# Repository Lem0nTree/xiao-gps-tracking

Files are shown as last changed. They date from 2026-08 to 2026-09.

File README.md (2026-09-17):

# XIAO GPS Tracker Smart Motion v2.1

**A compact, private, low-cost GPS tracker built from accessible maker hardware.**

The tracker logs positions locally without a SIM card, subscription, or cloud
account, then transfers them over bonded Bluetooth to an Android phone for
viewing or export.

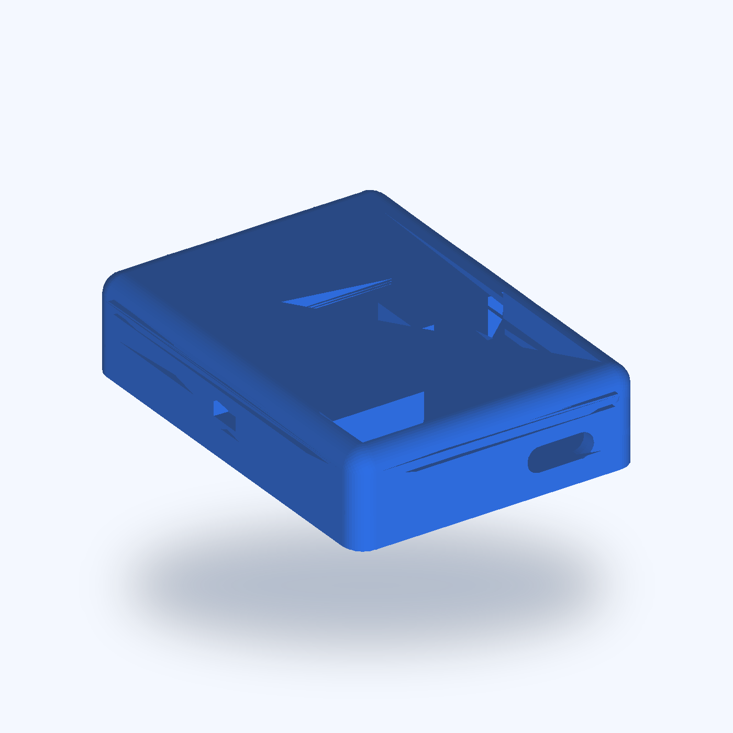
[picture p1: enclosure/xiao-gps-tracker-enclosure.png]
Render of the printable XIAO GPS Tracker enclosure


The assembled v2 hardware uses a Seeed Studio XIAO nRF52840, an ATGM336H GPS
receiver, a GY-521/MPU6050 motion sensor, a 1000 mAh 1S LiPo, and the native
Android companion app.

## Why this tracker?

- **No monthly fee** — no SIM card and no data plan.
- **Private by design** — tracks stay on the device and your phone.
- **Two recording modes** — Interval keeps scheduled logging; Smart Motion
  waits for sustained movement before acquiring a location.
- **Battery-conscious operation** — the firmware reduces receiver, UART, BLE,
  MCU, and flash activity where the assembled hardware permits.
- **Large offline history** — more than 104,000 positions fit in the onboard
  circular log.
- **Easy phone sync** — connect only when needed; logging continues without the
  phone.
- **Useful exports** — save a journey as GPX or CSV.
- **Open maps** — the app uses MapLibre and OpenFreeMap, with light and dark
  themes.
- **Pocket-size hardware** — an enclosure is included as STL, 3MF, and Fusion
  360 source.

## Smart Motion and Interval modes

Interval mode preserves the six saved schedules: 1, 15, or 30 minutes, or 1,
2, or 3 hours. Smart mode retains that saved interval but does not use the
interval scheduler while selected. A motion interrupt starts a short
accelerometer verification; sustained dynamic acceleration then starts GPS
acquisition, with a fresh valid location and UTC fix required before logging.
Smart Motion now has two tracking profiles:

- **Continuous** (default): the existing behavior, with a 120-second cooldown
  after a fix and another acquisition if movement continues.
- **Start & Stop** (Point-to-point): capture one point after confirmed movement starts, then
  one after **10 minutes without accelerometer activity**. Any new acceleration
  restarts the stop timer. No intermediate points are recorded. If movement
  resumes while acquiring the arrival point, that attempt is cancelled and a
  new ten-minute quiet period is required.

Point-to-point allows up to **5 minutes per GPS attempt**, requiring fresh GPS
position and UTC, at least **6 satellites**, and **HDOP ≤ 1.50**. These stricter
criteria favor better fixes; actual accuracy depends on reception. A failed
start attempt still waits for the stop; a failed arrival attempt rearms for the
next journey. It does not repeatedly retry while stationary. Both profiles keep
five-second motion confirmation and the saved sensitivity (Balanced by default).

Select **Smart motion → Tracking profiles** in the Android app. Point-to-point
requires app and firmware **2.1.0**. The updated app can still configure older
firmware using Continuous; it explains when a firmware update is needed. Older
apps retain log sync and Interval commands, but cannot read the new Smart status
or select Point-to-point. The detailed state machine, BLE packet layout, and
migration rules are in the [firmware notes](firmware/README.md).

## Actual v2 power and wiring model

The assembled hardware connects both the GPS receiver and the MPU6050 to the
XIAO `3V3` rail. It has a common ground, a 1000 mAh 1S LiPo connected to the
XIAO battery input, and no boost converter, load switch, GPS ON/OFF lead, or
physical GPS power gate. GPS supply is therefore electrically present whenever
the XIAO 3V3 rail is active.

Firmware reports these concepts separately:

- **Physical supply:** the receiver supply on this build; always connected
  while the XIAO rail is active.
- **Receiver activity:** whether the receiver is actively producing navigation
  data or is in a verified receiver-side standby state.
- **UART/parser activity:** whether the firmware has opened the GPS UART and is
  accepting NMEA data.

The firmware may probe the receiver's CASIC timed-standby capability after NMEA
has been established. It uses the optimization only after two complete
standby/resumption checks with valid navigation data; otherwise it keeps the
receiver running as required and reports that standby is unavailable. This is
an optimization, not a Smart-mode dependency. Current draw, standby timing,
and battery runtime still require physical measurement on the assembled unit.

## What you need

AliExpress changes listings and sellers frequently, so these are non-affiliate
search links rather than endorsements of a particular shop.

| Component | What to look for | AliExpress |
| --- | --- | --- |
| Seeed Studio XIAO nRF52840 | Standard nRF52840 board; Sense is not required | [Search](https://www.aliexpress.com/w/wholesale-xiao-nrf52840.html) |
| ATGM336H GPS receiver | 3.3 V-compatible module with `VCC`, `RX`, `TX`, and `GND` | [Search](https://www.aliexpress.com/w/wholesale-atgm336h-gps-module.html) |
| GY-521 / MPU6050 | Breakout with `VCC`, `GND`, `SDA`, `SCL`, and `INT` | [Search](https://www.aliexpress.com/w/wholesale-mpu6050-gy-521.html) |
| 1000 mAh 1S LiPo | Cell compatible with the XIAO battery input and enclosure | [Search](https://www.aliexpress.com/w/wholesale-1000mah-3.7v-lipo-battery.html) |

> [!IMPORTANT]
> Check dimensions, pin labels, logic levels, polarity, and the cell's charger
> requirements before ordering. Similar-looking marketplace modules are not
> always electrically equivalent.

## How it works

1. In Interval mode, the GPS obtains a position at the saved schedule and the
   XIAO saves it to onboard flash.
2. In Smart mode, the MPU6050 identifies a motion candidate, firmware verifies
   sustained movement, and the GPS obtains a fresh fix before a point is
   stored.
3. The Android app connects over bonded BLE to sync, browse, and export the
   route. Logging does not require the phone to remain connected.

The first bonded phone becomes the owner. A hardware recovery procedure can
change the owner without erasing the route history or saved wake settings.

## Android companion app

The Android app (`2.1.2`, versionCode `23`) shows tracker status, the
Interval/Smart selector, tracking profiles, map, and time-based route timeline.
Choose the GPS mode first: Interval shows the logging interval controls, while
Smart shows tracking profiles and hides the interval controls. The saved
interval is preserved and shown again when returning to Interval mode.
The dashboard separates tracker status, recording settings, and route history.
Its content scrolls on smaller screens while Connect and Sync remain accessible
at the bottom. Map gestures stay within the map; swipe outside it to scroll the
dashboard. Smart headlines show the motion state independently of GPS standby,
and any cooldown duration is explicitly the last value reported by the tracker.
It syncs the local log over BLE and exports tracks as GPX or CSV without sending
them to a cloud service. It also reports runtime fallback and receiver standby
capability when the firmware provides those statuses.

<p align="center">
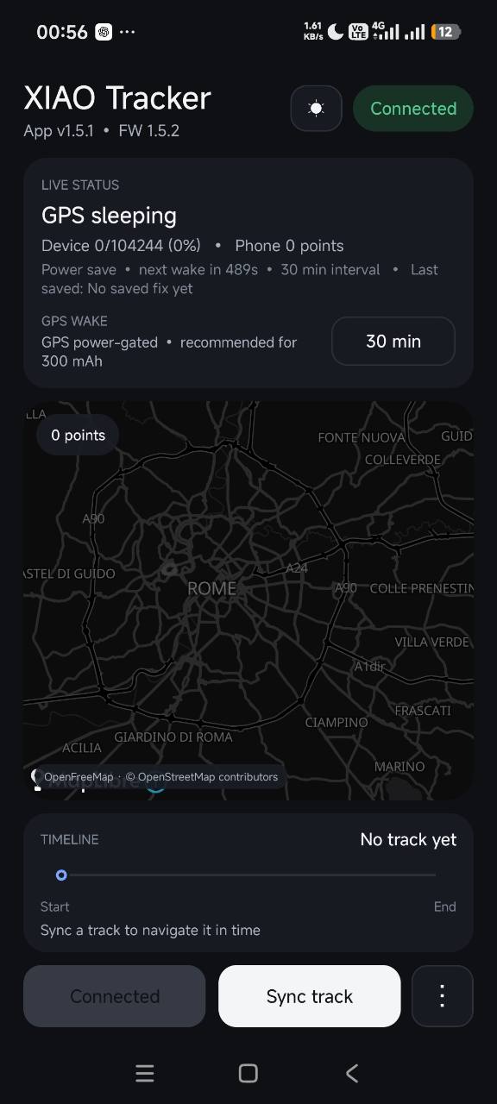
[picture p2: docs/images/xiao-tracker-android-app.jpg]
Earlier XIAO Tracker app interface, before the dashboard refresh
  
</p>

The screenshot above shows the earlier interface; an updated device capture is pending.

## Included in this repository

```text
firmware/   Arduino firmware, setup notes, and detailed wiring
android/    Native Android companion app
enclosure/  STL, 3MF, Fusion 360 source, render, and render script
docs/       README images and project media
```

### Start here

- [Firmware setup and technical details](firmware/README.md)
- [1000 mAh LiPo wiring guide](firmware/WIRING_1000MAH.md)
- [Android project](android/XiaoGpsTrackerApp)
- [Printable enclosure](enclosure/Seeed_GPS_Tracker.stl)
- [Release notes](RELEASE_NOTES.md)

For the firmware, use the non-mbed **Seeed nRF52 Boards** Arduino core and
change the example BLE pairing PIN before flashing. The Android project targets
JDK 17.

## Storage capacity

The tracker holds 104,244 GPS points before its circular log overwrites the
oldest entries. The table below applies to scheduled Interval mode; Smart mode
is event-driven, so its history length depends on movement and fix frequency.

| Interval mode setting | On-device history |
| --- | ---: |
| 1 minute | 72 days |
| 15 minutes | 3.0 years |
| 30 minutes | 5.9 years |
| 1 hour | 11.9 years |
| 2 hours | 23.8 years |
| 3 hours | 35.7 years |

Points already synced to Android remain in the phone archive even after the
tracker eventually overwrites its oldest records.

## Validation status

The software release defines the v2 state machine, BLE extension, metadata
migration, and runtime capability reporting. Physical validation is still
pending: sensor identity/address/interrupt checks, GPS 3.3 V operation and
NMEA checks, CAS12 standby cycles, current measurements, and sensitivity
calibration on the assembled hardware. No battery-runtime or power-saving
measurement is claimed yet. See [VALIDATION.txt](VALIDATION.txt) for the
release checklist.

This is a personal/offline logger, not a live anti-theft or emergency tracker:
it has no cellular connection and does not continuously report its location to
a remote service.

## Future development

The current BLE tracker is the foundation for planned variants built around the
same compact, local-first platform. These ideas are a roadmap and are **not
implemented in the current release**.

### RF version

- Add a **LoRa radio** for long-range, low-power position and status
  communication beyond normal Bluetooth range.
- Explore **Meshtastic integration** so compatible nodes can relay tracker data
  through an off-grid LoRa mesh.
- Retain local flash logging when a radio link or gateway is unavailable.

### SIM version

- Integrate a **SIM800L GSM/GPRS module** for remote position updates where
  compatible 2G service is still available.
- Add store-and-forward behavior so the tracker can upload queued positions
  after coverage returns.
- Redesign the power stage for the SIM800L's transmission-current peaks.

> [!NOTE]
> SIM800L depends on 2G service, which has already been retired in some
> countries and networks. Regional network compatibility must be checked before
> developing or buying parts for this variant.

### Long-autonomy version

- Replace the pouch cell with a protected, quality **18650 Li-ion cell** for
  substantially more stored energy.
- Develop a larger enclosure with safe cell retention and service access.
- Profile every always-on load and tune the GPS, BLE, LoRa, or Meshtastic duty
  cycle for extended unattended operation.

Future autonomy targets will be published only after complete hardware builds
have been measured under representative conditions.

## License

See [LICENSE](LICENSE).

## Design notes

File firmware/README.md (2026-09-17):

# XIAO GPS Tracker firmware

Technical setup notes for the Seeed Studio XIAO nRF52840 firmware. For the
project overview and Android app, return to the [main README](../README.md).

## Arduino setup

Use the non-mbed **Seeed nRF52 Boards** Arduino core and select:

```text
Tools -> Board -> Seeed nRF52 Boards -> Seeed XIAO nRF52840
```

Install these Arduino libraries:

1. TinyGPSPlus
2. Adafruit SPIFlash
3. Adafruit TinyUSB Library

Open [XiaoGpsTracker/XiaoGpsTracker.ino](XiaoGpsTracker/XiaoGpsTracker.ino).
Arduino Serial Monitor uses **115200 baud** and the GPS UART uses **9600 baud**.

Before deployment, change the example six-digit BLE pairing PIN:

```cpp
static const char BLE_PAIRING_PIN[] = "482731";
```

## Actual v2 wiring

The assembled build uses a 1000 mAh 1S LiPo, a GY-521/MPU6050 at I²C address
`0x68`, and an ATGM336H receiver powered from the XIAO `3V3` rail. Grounds are
common. The GPS supply is continuously connected while the XIAO 3V3 rail is
active; this build has no boost converter, load switch, GPS ON/OFF lead, or
physical GPS power gate.

| XIAO pin or rail | Connect to | Notes |
| --- | --- | --- |
| `BAT` | LiPo positive; LiPo negative to `GND` | 1S cell; check polarity and charger suitability |
| `3V3` | MPU6050 `VCC` and GPS `VCC` | Use the documented 3V3 rail |
| `GND` | MPU6050 `GND` and GPS `GND` | One common ground |
| `D2` | MPU6050 `INT` | Motion interrupt |
| `D4` | MPU6050 `SDA` | I²C data |
| `D5` | MPU6050 `SCL` | I²C clock |
| `D6` | GPS `RX` | XIAO TX -> receiver RX |
| `D7` | GPS `TX` | Receiver TX -> XIAO RX |
| `D0` | Owner-reset test point | Hold to `GND` during boot for 5 seconds |
| `D1` | No connection | Unused/reserved for a future design |
| `D3`, `D8`–`D10` | No connection | Free in the assembled build |

Leave the GY-521 `AD0`, `XDA`, and `XCL` pins unconnected. The default `AD0`
state selects address `0x68`. Leave GPS `PPS` unconnected unless a future
firmware design explicitly uses it.

See the detailed [1000 mAh LiPo wiring guide](WIRING_1000MAH.md) before
connecting power. Do not connect a battery, sensor, or receiver through D1;
there is no external power-control circuit in this assembly.

## Recording modes

The persisted wake modes are:

```text
WAKE_MODE_INTERVAL = 0
WAKE_MODE_SMART    = 1
```

### Interval mode

Interval mode retains the existing six persisted schedules:

```text
1 minute
15 minutes
30 minutes (default)
1 hour
2 hours
3 hours
```

The GPS obtains a valid location for each scheduled point. The legacy
`CMD_SET_INTERVAL` command also selects Interval mode, preserving the expected
behavior of older Android apps.

### Smart Motion mode

Smart mode leaves the saved interval untouched but does not use the interval
scheduler while selected. An MPU6050 interrupt moves the tracker from `ARMED`
to `VERIFYING`. Verification samples dynamic acceleration (gravity removed) at
20 Hz for 5 seconds, or 100 samples. A candidate is accepted when at least 60
samples are active and no quiet gap exceeds 1 second. A rejected candidate
returns to `ARMED` without a GPS acquisition.

#### Continuous profile (default)

An accepted candidate moves to `ACQUIRING`. Firmware requires a fresh valid
location and UTC from the GPS within 90 seconds, then stores the point and
enters a 120-second cooldown. Recent accelerometer activity and reliable GPS
speed/displacement determine whether movement continues. Continued movement
can start another acquisition; when movement stops, the tracker returns to
`ARMED`. A failed acquisition is retried after the cooldown only when movement
is reconfirmed.

#### Point-to-point profile

After the same five-second acceleration confirmation, capture one departure
point. Then enter `WAITING_FOR_STOP` with GPS parsing inactive. Every subsequent
MPU motion event resets the stop timer; there is no two-minute capture in this
profile. After exactly 600 seconds with no accelerometer activity, enter
`ACQUIRING_STOP` and attempt one arrival point. GPS speed and drift do not reset
the acceleration timer. A GPS fix also does not reset it.

Each acquisition allows **300 seconds**, instead of Continuous's 90 seconds.
It requires a fresh post-start location and UTC plus all of these conditions:

- location, date, time, satellite count, and HDOP no older than 2 seconds;
- at least 6 satellites;
- HDOP greater than zero and no greater than 1.50.

These limits favor higher-quality navigation but do not guarantee positional
accuracy. A fix arriving at or after the acquisition deadline is not stored.
A failed departure attempt still waits for arrival. A successful or timed-out
arrival rearms for the next departure; no repeated stationary attempts occur.
If acceleration resumes during arrival acquisition, cancel that acquisition
before storing a point and wait for another complete ten-minute quiet period.
Point-to-point does not use CAS12 cooldown slices and retires any in-flight
startup probe before its departure acquisition.
Booting or changing settings rearms the runtime; in-progress journeys are not
persisted across reboot.

The Android Smart Motion settings display **Tracking profiles** with
**Continuous** and **Point-to-point**. Sensitivity remains an underlying saved
calibration setting; the new app preserves it when changing profile.

Smart sensitivity presets are starting calibration values, not measured final
thresholds:

| Preset | Wire value | Starting dynamic-acceleration threshold |
| --- | ---: | ---: |
| High | `0` | 80 mg |
| Balanced (default) | `1` | 160 mg |
| Low | `2` | 300 mg |

The firmware initializes the MPU by direct register access, checks identity and
critical register read-back, and arms its interrupt. If that initialization or
the interrupt fails, the saved Smart selection is preserved but that boot runs
Interval behavior and reports `runtimeIntervalFallback`.

### Motion rearm diagnostic build

The current startup banner is `FW diagnostic build: ble-startup-1`. The
post-v2.0 motion-rearm diagnostics remain available. Serial output now includes saved mode, actual runtime
mode, fallback, Smart state, the real Smart cooldown, D2 level, interrupt count,
motion-event count, and verification sample counts/rejection reasons. An
Interval `nextWake` countdown is printed only when Interval actually runs.
The legacy INFO wake countdown is zero while Smart runs; use Smart Info for
its cooldown. Android's displayed state is the last BLE read-back, not a
continuous live indication.

The patch recovers a latched-high MPU interrupt even when the rising edge was
missed, checks the Seeed core's interrupt attachment result, checks interrupt
clearing failures, and rearms the sensor on return to ARMED. Continued movement
at a successful fix's cooldown expiry starts the next acquisition directly.
Data-ready interrupts supply verification timing; software no longer discards
fresh samples just because readout jitter makes successive reads less than
50 ms apart.

The armed profile uses `DLPF_CFG=0`, `MOT_DUR=1` per the low-power motion
configuration flow in the [InvenSense product specification, section 8.1](https://hw101.tbs1.de/mpu6050/doc/mpu6050.pdf).
This replaces the initial plan's 100-count hardware-duration setting: that
setting is not validated as a 100 ms debounce in 5 Hz cycle mode. The
five-second software confirmation remains the sustained-movement filter.
The candidate threshold follows that flowchart's 32 mg/LSB scale, rounding
down to codes 2/5/9 for High/Balanced/Low. The previous Balanced code of 80
would correspond to 2560 mg at that scale. Documentation revisions disagree
on motion-threshold units; actual module calibration is still pending. The
software verifier retains the exact 80/160/300 mg presets regardless of the
hardware wake threshold.

Run the focused host regression checks from the repository root:

```sh
python3 firmware/tests/test_motion_runtime.py
python3 firmware/tests/test_tracking_profiles.py
```

These compile actual scheduler/verifier and profile/GPS-save function bodies
with GCC/G++ and fake peripherals/clock. They cover repeated cooldowns, motion after
rearming, missed interrupt edges, jittered 20 Hz samples, quiet rejection,
failure retry, rollover, Interval scheduling, Point-to-point stop timing and
cancellation, quality gating, metadata migration, and settings rollback. They do not validate the
physical MPU, GPS, BLE stack, or flash writes.

## GPS activity and CAS12 standby

The firmware keeps these states distinct:

- **Physical supply:** electrically present on `3V3` whenever the XIAO rail is
  active; there is no physical GPS power-off control on this hardware.
- **Receiver activity:** whether the ATGM336H is navigating or in receiver-side
  timed standby.
- **UART/parser activity:** whether `Serial1` is open and NMEA is being
  accepted by the firmware.

After normal NMEA has been observed, firmware can probe the receiver's CASIC
`$PCAS12` timed-standby capability. It attempts two controlled standby cycles
and accepts the capability only if each cycle shows the expected NMEA silence,
resumption, fresh RMC/GGA sentences, and subsequent valid navigation. A failed
probe is marked unavailable for the boot; it is not continuously retried.
When unavailable, the receiver remains active as required and the status does
not claim a power saving that was not verified. CAS12 is an optimization only;
Smart motion and GPS acquisition do not depend on it.

Standby slices may be selected from the firmware's short/medium/long profiles
(30, 60, or 120 seconds). Thirty seconds is a compatibility workaround, not a
claim that it is optimal. Slice current and resume latency must be measured on
the actual receiver before choosing a production default.

## Storage and metadata

The XIAO's 2 MiB QSPI flash contains a circular log with 104,244 records. Each
20-byte record contains:

- sequence number;
- UTC Unix timestamp;
- latitude and longitude multiplied by 10^7;
- HDOP multiplied by 100;
- satellite count;
- CRC-8.

The 32-byte metadata record is version 3. It retains the owner identity and
interval and uses three previously reserved bytes for `wakeMode`,
`smartSensitivity`, and `trackingProfile`. Version-1 metadata migrates to
Interval/Balanced/Continuous while preserving owner and interval. Version-2
metadata preserves mode and sensitivity and defaults to Continuous, regardless
of the old reserved profile byte. Valid v1/v2 settings are decoded in RAM
without any flash erase/write during boot. The next successful settings or
owner save persists metadata v3. An optional format upgrade therefore cannot
prevent Bluetooth startup if the stored settings can already be read.
GPS records remain byte-for-byte compatible.

Owner reset (D0 held low during boot) clears only ownership. It preserves the
route history, interval, wake mode, sensitivity, and tracking profile. Clearing
the route also preserves these settings; neither operation is a factory reset.

## BLE framing and profile protocol v3

Packets use the existing frame:

```text
magic A5 5A | type:u8 | len:u16 little-endian | payload | CRC16-CCITT
```

The CRC covers `type`, `len`, and `payload`. Existing command and response
types remain available, including the 65-byte `INFO` response. Command IDs
remain the same as v2:

```text
CMD_GET_SMART_INFO   = 0x06   payload: empty
CMD_SET_SMART_CONFIG = 0x07   payload: mode:u8, sensitivity:u8, profile:u8
RSP_SMART_INFO       = 0x85   payload: exactly 13 bytes, protocolVersion = 3
```

`CMD_SET_SMART_CONFIG` returns the normal ACK and the client reads Smart Info
back to verify persisted settings. The v3 command requires three bytes;
legacy two-byte commands remain accepted and explicitly select Continuous.
Profile values are `0` Continuous and `1` Point-to-point. Invalid values or
lengths are rejected before any settings change.

The v3 `RSP_SMART_INFO` keeps the v2 field offsets and appends the profile:

| Offset | Field | Encoding |
| ---: | --- | --- |
| 0 | `protocolVersion` | `u8` |
| 1 | `mode` | `u8` (`0` Interval, `1` Smart) |
| 2 | `sensitivity` | `u8` preset (`0` High, `1` Balanced, `2` Low) |
| 3 | `motionState` | `u8` state code |
| 4 | `confirmationSeconds` | `u8` |
| 5 | `standbySliceSeconds` | `u8` |
| 6–7 | `fixCooldownSeconds` | `u16` little-endian; 120 Continuous, 0 Point-to-point |
| 8–9 | `cooldownRemainingSeconds` | `u16` little-endian |
| 10 | `flags` | `u8` bit field |
| 11 | `lastWakeReason` | `u8`; 0 none, 1 motion, 2 retry, 3 stop |
| 12 | `trackingProfile` | `u8`; 0 Continuous, 1 Point-to-point |

Motion state codes 0–5 retain their v2 meanings; 6 is `WAITING_FOR_STOP` and
7 is `ACQUIRING_STOP`. The cooldown remaining field describes only a Continuous
cooldown, not the Point-to-point quiet timer.

The defined flag bits are:

```text
0x01 MPU_PRESENT
0x02 MPU_INTERRUPT_ARMED
0x04 CAS12_VERIFIED
0x08 CAS12_ACTIVE
0x10 RUNTIME_INTERVAL_FALLBACK
0x20 GPS_RECEIVER_ACTIVE
```

There is deliberately no physical-GPS-power-off flag for this assembly. A
runtime fallback means the saved Smart setting remains available for a later
boot or hardware configuration; it does not silently rewrite the user's mode.

Older apps can still bond, read the legacy INFO packet, sync records, clear
logs, and set the six interval values. They cannot configure or display Smart
profiles or parse the v3 Smart Info until upgraded to app 2.1.0. The updated
app also accepts the v2 12-byte Smart Info, uses legacy setters for that
firmware, and offers Continuous only until firmware is upgraded.

## BLE behavior and security

The first successfully bonded phone becomes the owner. Tracker commands require
an encrypted, bonded owner connection. Unknown or unbonded phones are
disconnected. The app disconnects after BLE inactivity so the phone need not
stay connected while logging.

To replace the owner phone without deleting GPS history or wake settings:

1. Power off the tracker.
2. Connect **D0 to GND**.
3. Power or reset it and hold D0 low for at least five seconds.
4. Release D0.
5. Pair the replacement phone.

## Bluetooth startup diagnostics

Firmware 2.1.1 verifies the BLE stack, UART service, advertising payload, and
advertising start result. Serial output claims advertising only after a
successful start. With USB connected, open Serial Monitor at 115200 baud and
restart the tracker. A `FATAL:` line identifies a startup stage that failed;
these lines repeat every five seconds. In normal operation, `BLE DIAG` reports
`advertising=0/1` and `connected=0/1` every five seconds alongside GPS status.
Firmware 2.1.2 uses startup banner `flash-wake-1`. Pairing PINs are not logged.

An MCU reset or USB firmware upload does not necessarily remove power from
the onboard flash. The chip can remain in deep power-down while the sketch's
RAM state resets. Firmware 2.1.2 sends `0xAB` (Release from Deep Power-down)
using GPIO SPI **before** initializing QSPI, then waits 50 microseconds before
flash detection. This also avoids initializing the QSPI controller against an
unresponsive sleeping chip. The wake operation does not erase stored data.
See the [Puya P25Q16H datasheet](https://www.puyasemi.com/download_path/%E6%95%B0%E6%8D%AE%E6%89%8B%E5%86%8C/Flash%20%E8%8A%AF%E7%89%87/P25Q16H_Datasheet_V2.1.pdf),
pages 44–46 (`tRES1` maximum 8 microseconds).

For an enclosed tracker reporting `FATAL: P25Q16H QSPI flash not detected`,
upload firmware 2.1.2 normally over USB; battery removal and access to the
reset button are not required for this recovery path. Android 2.1.1 remains
compatible. Successful startup prints `QSPI JEDEC=0x856015` for P25Q16H and
then `Advertising as XIAO-GPS`. If initialization still fails, copy the new
repeating `FATAL: QSPI flash not detected after wake` line, including its
`JEDEC` and `read` fields. A completed ID transfer alone does not prove that
a flash chip responded.

The Android 2.1.1 scanner preserves scan failures and connection/disconnection
messages after discovery; its 12-second “not found” timeout applies only to the
scan that is still active. These diagnostics distinguish no advertisements
from a discovered tracker whose connection or pairing subsequently failed.

## Validation status

Source-level protocol, metadata, and state-machine checks can be performed
without a board. Physical validation remains pending for the assembled unit:
MPU `WHO_AM_I`, address, register read-back, and interrupt; GPS 3.3 V operation,
UART/NMEA, and valid navigation; two CAS12 standby/resumption cycles; current
draw in Interval and Smart states; and sensitivity calibration while stationary,
walking, in a city, and in smooth driving. See [VALIDATION.txt](../VALIDATION.txt)
for the release checklist. Do not use software defaults as measured hardware
results.

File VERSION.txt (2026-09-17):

XIAO GPS Tracker Smart Motion
Firmware: 2.1.2
Android app: 2.1.2
Android versionCode: 23
Wake modes: Interval (0), Smart motion (1)
Protocol INFO: 65-byte layout unchanged
Protocol commands: CMD_GET_SMART_INFO 0x06; CMD_SET_SMART_CONFIG 0x07
Protocol v3 response: RSP_SMART_INFO 0x85 (13-byte payload; profile at byte 12)
CMD_SET_SMART_CONFIG payload: mode:u8, sensitivity:u8, profile:u8 (3 bytes)
Legacy 2-byte config accepted; selects Continuous
Default GPS interval: 1800 seconds (30 min)
Default Smart sensitivity: Balanced (160 mg starting value)
Tracking profiles: Continuous (0), Point-to-point (1); default Continuous
Point-to-point: 600s quiet stop timer; 300s acquisition; >=6 sats, HDOP<=1.50
Metadata: version 3 on save; valid v1/v2 loaded read-only during boot
Metadata fields: wakeMode + smartSensitivity + trackingProfile in reserved bytes
Hardware: 1000 mAh 1S LiPo; GY-521/MPU6050 @0x68; GPS on 3V3; D1 unused

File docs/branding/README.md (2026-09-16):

# Launcher icon

A white location pin flows into a route with a sky-blue endpoint, on cobalt blue.
No text, Wi-Fi arcs, shadows, or baked-in texture.

## Files

- `generated-concept.png`: selected concept from the built-in image_gen tool.
- `launcher.svg`: clean, manually reconstructed vector artwork for deterministic exports.
- `launcher-preview.png`: 512px preview rendered from that SVG.
- `../../android/XiaoGpsTrackerApp/app/src/main/res/drawable/ic_launcher_foreground.xml`:
  matching Android vector, with 108dp layers and artwork inside the central 66dp circle.
- `mipmap-anydpi-v26`: adaptive launcher resources for Android 8+.
- `mipmap-anydpi-v33`: explicit monochrome layer for supported themed launchers.
- Density PNGs: standard and circular compatibility icons, 48/72/96/144/192px.

Android's [adaptive icon guidance](https://developer.android.com/develop/ui/compose/system/icon_design_adaptive)
defines layer geometry, mask safety, and monochrome behavior. The vector foreground
has transparent negative space; the launcher applies its own mask to the solid background.
The two-color foreground's alpha also supplies the themed monochrome silhouette.

## Regenerate compatibility PNGs

Install `@resvg/resvg-js@2.6.2` in a temporary directory outside the project, then run:

```sh
node scripts/render_launcher_icons.cjs /path/to/node_modules/@resvg/resvg-js
```

Keep the paths and scale in the SVG and Android vector in sync. Only exports use
rounded/circular masks; the adaptive background remains full-bleed.
The app manifest and application ID are unchanged. Only an APK update is needed.

## Image-generation provenance

Skill: imagegen. Mode: built-in tool, not API/CLI fallback. The generated raster
was used as the design reference; native vectors remove artifacts and guarantee
sharp edges and predictable launcher masking.

Initial prompt:

> Use case: logo-brand. Asset type: production Android adaptive launcher icon foreground for XIAO GPS Tracker. Create ONE polished, minimal, flat graphic symbol: a bold white GPS location pin whose lower tip flows into a short rounded winding route, ending in one small sky-blue waypoint dot. The pin has a clean genuinely transparent circular cutout. Strong simple silhouette, smooth precise edges, chunky strokes legible at 48 pixels, balanced negative space. Existing app uses cobalt blue and white. This foreground will be placed over a solid cobalt blue background by Android. Canvas: square 1024 x 1024 with a GENUINELY TRANSPARENT background and alpha channel, not a checkerboard painting. Center the complete symbol, including route and dot, entirely inside a central circle of diameter 580 pixels; generous transparent margins on all four sides are mandatory for Android adaptive icon masks. White main mark, pale sky-blue waypoint accent only. No text, no letters, no WiFi arcs, no satellite drawing, no maps, no border, no rounded-square tile, no background, no shadow, no glow, no texture, no 3D, no mockup, no watermark. Deliver a single finished foreground asset, not a sheet of options.

Final refinement prompt (input: first generated foreground):

> Refine this image into a finished production Android launcher icon. Keep exactly the location-pin flowing into a short curved route ending in a sky-blue dot, but fix all ragged edges and stray pixels: perfectly smooth flat graphic silhouette, opaque pure-white mark with a perfectly circular clean opening. Replace ALL transparency, holes, exterior and background with a uniform solid cobalt blue #225DD8. Absolutely no flecks, texture, noise, shadows, glow or gradients. Full-bleed square blue canvas, no rounded corners, no border, no mockup. Center and scale the entire white symbol and dot so ALL non-blue artwork fits inside the central circular safe area whose diameter is 58% of canvas width. The background fills the whole canvas edge to edge. No text or extra elements. Deliver a single clean square icon.

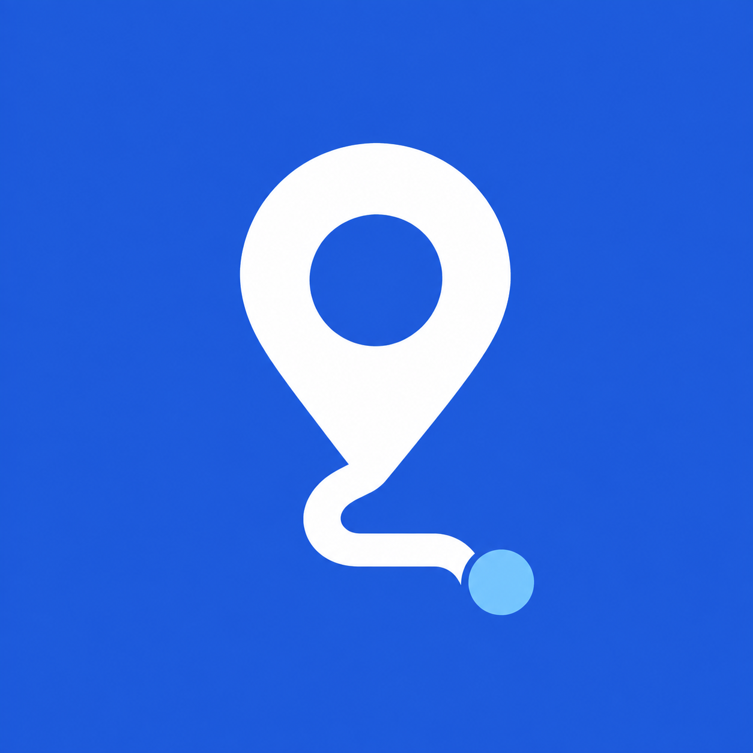
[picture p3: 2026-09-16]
docs/branding/generated-concept.png

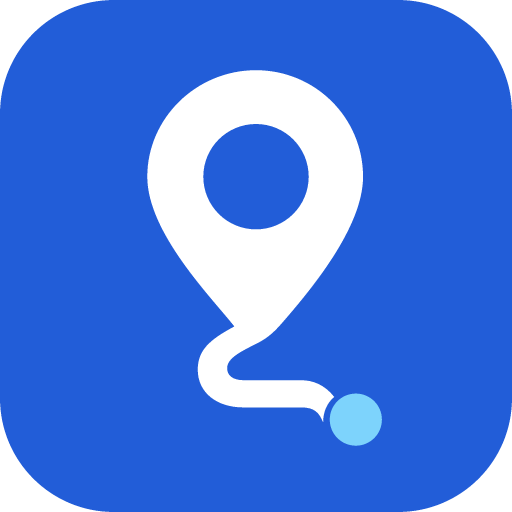
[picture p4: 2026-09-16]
docs/branding/launcher-preview.png

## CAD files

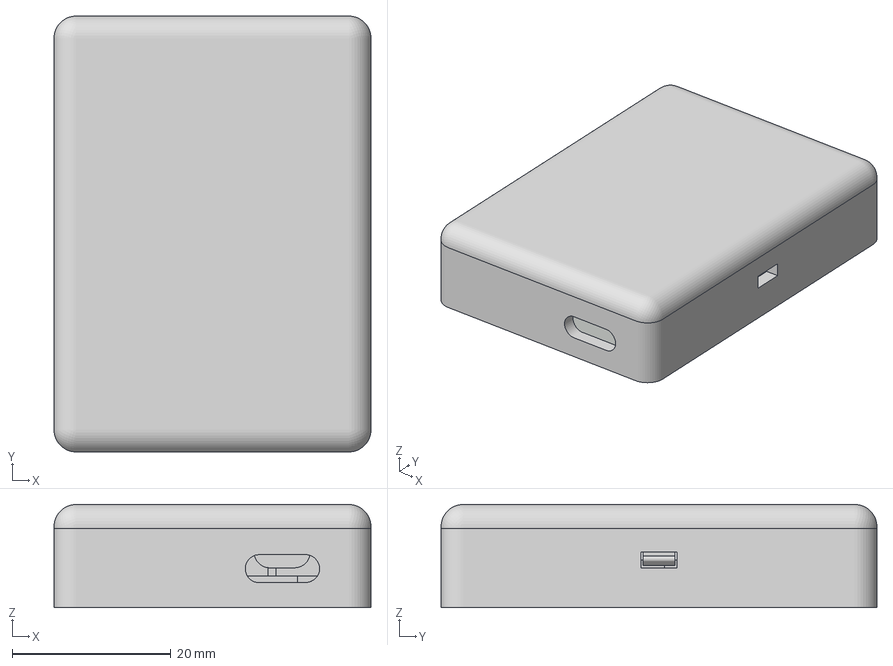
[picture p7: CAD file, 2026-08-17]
enclosure/Seeed_GPS_Tracker.3mf
40.0 x 55.0 x 13.0 mm
top

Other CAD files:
enclosure/Seeed_GPS_Tracker.f3z
enclosure/Seeed_GPS_Tracker.stl

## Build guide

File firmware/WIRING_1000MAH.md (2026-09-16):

# 1000 mAh LiPo wiring

This guide matches the assembled Smart Motion v2 hardware: a 1S 1000 mAh LiPo,
an XIAO nRF52840, a GY-521/MPU6050, and an ATGM336H GPS receiver. The receiver
and motion sensor share the XIAO `3V3` rail and ground.

## Connections

```text
1000 mAh 1S LiPo
   +------------------------------> XIAO BAT
   +------------------------------> XIAO GND (LiPo negative)

MPU6050 / GY-521                  XIAO
VCC -----------------------------> 3V3
GND -----------------------------> GND
SDA -----------------------------> D4 / SDA
SCL -----------------------------> D5 / SCL
INT -----------------------------> D2

ATGM336H GPS                      XIAO
VCC -----------------------------> 3V3
GND -----------------------------> GND
TX  -----------------------------> D7 / RX
RX  <----------------------------- D6 / TX
PPS -----------------------------> not connected

Owner-reset test point: D0 -> GND only when performing the boot reset procedure
D1: not connected (unused/reserved)
```

The GY-521 default I²C address is `0x68`; leave `AD0`, `XDA`, and `XCL`
unconnected. D3 and D8–D10 are free in this assembly.

## Power and signal checks

- Verify the LiPo connector polarity before connecting it to the XIAO battery
  input. Do not connect the raw cell to the sensor or GPS signal rail.
- Confirm that the GPS and MPU VCC pins are on XIAO `3V3`, with one common
  ground.
- GPS serial communication is 9600 baud. Cross TX and RX as shown above.
- D1 is unused. Do not wire it to a supply, receiver control input, or another
  power circuit.
- This assembly has no boost converter, load switch, GPS ON/OFF connection, or
  physical GPS power gate. The GPS supply is electrically present whenever the
  XIAO 3V3 rail is active.
- Check the cell manufacturer's permitted charge profile and the charger's
  suitability before charging. Do not charge a damaged, swollen, or unprotected
  LiPo cell.

Firmware can reduce UART/parser and receiver activity and may use CASIC timed
standby only after a runtime capability probe. Those logical states are not a
physical removal of GPS supply.

## Validation status

The wiring is the documented target assembly; physical checks remain pending.
Before relying on the tracker, verify MPU identity/address/register read-back
and interrupt operation, GPS 3V3 operation and NMEA/navigation, and the two
CAS12 standby/resumption cycles. Measure whole-device current in both wake
modes and calibrate Smart thresholds on representative stationary, walking,
city, and smooth-driving runs. No current, runtime, or calibration result is
claimed by this wiring guide.

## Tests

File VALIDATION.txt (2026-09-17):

XIAO GPS Tracker Smart Motion v2.1 validation record

This record separates software/source checks from tests that require the
assembled hardware. It contains no measured current, runtime, or calibration
result.

FLASH STARTUP RECOVERY 2.1.2 (2026-09-17)

OBSERVED - User's serial trace repeats "FATAL: P25Q16H QSPI flash not detected".
           This locates the reported failure before metadata loading and BLE.
           The metadata-migration simulation below is a separate defect, not
           the startup stage failing in this trace.
PASS - Source/dependency review: firmware puts the flash in deep power-down;
       Adafruit SPIFlash 5.1.1 attempts JEDEC detection without first waking
       it. The RAM sleeping flag resets independently of externally powered
       flash, and Seeed core QSPI activation can time out while it sleeps.
PASS - Target build with Seeed nRF52 1.1.13, Seeeduino:nrf52:xiaonRF52840:
       172776 bytes program, 19380 bytes RAM.
PASS - Existing motion runtime and tracking profile host suites after patch.
PASS - test_flash_startup.py compiles the actual startup functions against a
       GPIO/flash model: original detection fails asleep; patched warm resets,
       cold boot and repeated resets pass, and absent flash still fails.
       Checks mode-0 0xAB framing, pin directions, CS byte boundary and wake
       delay before QSPI ownership. No erase/write API is available to the fake.
PASS - Independent review of wake timing, board pins and QSPI handover.
PENDING - On-device recovery following USB upload, with the battery connected.
          No physical tracker is attached to this build host. The trace does
          not by itself distinguish a sleeping chip from hardware/board issues.

ANDROID APK 2.1.1 BUILD (2026-09-16)

PASS - Installed a local headless ARM64 toolchain and completed a clean Gradle
       assembleDebug plus testDebugUnitTest: 44 tasks, all 11 tests passed.
       Uses API 36, Build Tools 35.0.0, OpenJDK 21, and AGP-matched Google AAPT2
       through QEMU user mode (Debian's ARM64 AAPT2 cannot read API 36 resources).
PASS - APK signature verified by apksigner; packaged version 2.1.1/code 22.
       This supersedes the earlier missing-SDK build blockers below.

BLUETOOTH STARTUP / SCAN FIX 2.1.1 (2026-09-16)

PASS - Reproduced against firmware 2.1.0 in the fake-flash host harness:
       valid v2 metadata plus an erase failure makes loadOwnerLock fail,
       which setup treats as fatal before Bluetooth starts.
PASS - Patched firmware loads valid v1/v2 metadata without erases or writes,
       preserving original flash bytes and owner/settings even when writes
       fail. An explicit successful settings save still upgrades to v3.
PASS - Existing firmware motion/profile host suites pass after the repair.
PASS - Target build with Seeed nRF52 1.1.13, Seeeduino:nrf52:xiaonRF52840:
       172488 bytes program, 19380 bytes RAM.
PASS - Android protocol/presentation JVM suite: 11 tests (Kotlin 2.3.0,
       JUnit 4.13.2), including tracking-profile compatibility.
PASS - Changed BleManager compiles against Android API 36 and AndroidX Core
       1.17.0. Independent source review confirms active-session checks and
       timeout cancellation for discovery, scan failure, stop and restart.
BLOCKED - Full Android Gradle test/APK build: no configured Android SDK.
          JVM tests and the direct BleManager compile do not cover real BLE.
ADDED - Checked BLE stack/service/advertising initialization and repeating
        fatal-stage output; periodic actual advertising/connection diagnostics.
PENDING - Physical confirmation of the reported connection problem: no board
          USB serial trace or radio observation is available in this workspace.
          The simulated startup failure is established; it is not proof that
          flash writes failed on the user's tracker.

POINT-TO-POINT PROFILE (2026-09-16)

PASS - Firmware 2.1.0 target build with Seeed nRF52 core 1.1.13,
       Seeeduino:nrf52:xiaonRF52840: 172040 bytes program, 19380 bytes RAM.
PASS - python3 firmware/tests/test_motion_runtime.py: actual scheduler/verifier
       bodies pass Continuous regressions plus Point-to-point movement without
       periodic GPS, exact 600-second stop, motion cancellation during arrival,
       five-minute timeouts, quiet-clock rollover, and zero timestamp handling.
PASS - python3 firmware/tests/test_tracking_profiles.py: actual persistence and
       GPS-save bodies pass v1/v2 migration, profile reload, owner-reset
       preservation, invalid configuration rejection, failed-save RAM rollback,
       fresh quality filtering, one departure/arrival, deadline ordering, and
       cancellation of a startup CAS12 probe before endpoint acquisition.
       GCC/G++ tests use fake peripherals; C++ compiler unpacked under /tmp.
PASS - Firmware review confirms 13-byte Smart Info v3, profile at byte 12,
       legacy 2-byte setter selects Continuous, v3 3-byte setter validates
       profile before saving. GPS record and INFO layouts remain unchanged.
PASS - Android ProtocolTest and TrackerPresentationTest: all 11 JUnit tests
       passed using Kotlin 2.3.0 compiler, JVM target 17, JDK 21, JUnit 4.13.2.
       This standalone run compiled GpsRecord, Protocol, TrackerPresentation,
       and both test classes; it does not compile the Activity or Android UI.
PASS - Android resource XML parses; independent review checked profile dialog,
       legacy-firmware gating, status presentation, and profile-aware readback.
BLOCKED - Full Android Gradle unit-test/APK build: temporary JDK runs Gradle,
          but task dependencies fail because the Android SDK is unavailable.
PENDING - Physical departure/arrival tests, smooth travel vs no acceleration,
          real GPS availability/accuracy, stop/resume near the 10-minute
          boundary, power-cycle persistence, and phone-to-board BLE readback.

Entries below record earlier releases/changes and their original test results.
Where behavior changed, the Point-to-point entry above supersedes them.

ANDROID LAUNCHER ICON REFRESH (2026-09-16)

PASS - Resource XML parses. Native SVG and Android vector use identical paths.
PASS - Adaptive resources for API 26 and explicit themed monochrome resources
       for API 33 resolve to the new foreground and background.
PASS - All ten standard/round density PNGs have the expected 48/72/96/144/192 px
       dimensions and transparent corners. Rendered artwork stays inside the
       adaptive 33 dp safe radius (measured maximum approximately 30.58 dp).
PASS - Visual inspection of the rendered 512 px preview and 48 px round icon.
PENDING - Android build and launcher/device checks; Java/JDK unavailable here.
          See docs/branding/README.md for design sources and regeneration.

ANDROID DASHBOARD REFRESH (2026-09-16)

PASS - Static resource checks: XML parsing, unique view IDs, single ScrollView
       child, bottom action buttons outside the scroll area, mode selector
       before conditional interval controls, 48 dp minimum button targets,
       and status text without line truncation.
ADDED - TrackerPresentationTest covers motion headlines, receiver-state
        independence, sensor faults, fallback priority, and Interval behavior.
BLOCKED - APK compilation and JUnit execution: Java/JDK is absent on this host.
PENDING - Device/emulator visual and gesture checks: light/dark themes, 320 dp
          screen width, landscape, large fonts, map pan/pinch vs page scrolling,
          empty/populated route, BLE reconnect, and mode switching.

MOTION REARM PATCH (2026-09-16)

PASS - Host checks execute extracted production scheduler/verifier bodies with
       a fake clock and peripherals, compiled with GCC. Focused checks cover
       latched-high IRQ recovery, jittered verification, three consecutive
       120-second cooldowns, stopped/restarted motion, failed-fix retry,
       millis rollover, stationary quiet-gap rejection, obsolete Interval
       deadline isolation, normal Interval wake, and I2C failure fallback.
       Run: python3 firmware/tests/test_motion_runtime.py
PASS - Actual MPU profile functions tested with fake registers: low-power
       settings, 20 Hz verification profile, and status-clear I2C failures.
PASS - The pre-patch HEAD fails the latched-high interrupt recovery test;
       the modified source passes it (test script --baseline reproduces).
PASS - Diagnostic build motion-rearm-1 compiled for
       Seeeduino:nrf52:xiaonRF52840, core 1.1.13, Arduino CLI 1.5.1,
       TinyGPSPlus 1.0.3 and Adafruit SPIFlash 5.1.1:
       171016 bytes program storage, 19380 bytes dynamic memory.
PENDING - Reproduce the reported one-fix-then-stuck failure and verify the
          corrected behavior on the user's assembled tracker. Host tests do
          not establish physical interrupt delivery or sensor calibration.

IMPLEMENTED / SOURCE-CONTRACT CHECKS

PASS - Release identifiers are firmware 2.0.0, Android 2.0.0, versionCode 20.
PASS - Wake modes are Interval = 0 and Smart = 1; the six persisted Interval
       values remain 60, 900, 1800, 3600, 7200, and 10800 seconds.
PASS - Smart mode retains the saved interval while selected; legacy
       CMD_SET_INTERVAL (0x05) selects Interval mode.
PASS - v2 protocol IDs are CMD_GET_SMART_INFO = 0x06,
       CMD_SET_SMART_CONFIG = 0x07, and RSP_SMART_INFO = 0x85.
PASS - CMD_SET_SMART_CONFIG has exactly the two-byte mode:u8,
       sensitivity:u8 payload; RSP_SMART_INFO has exactly 12 bytes in the
       documented field order.
PASS - The legacy 65-byte INFO response and existing log record layout remain
       compatible with earlier clients.
PASS - Metadata version 2 consumes two reserved bytes for wakeMode and
       smartSensitivity; version-1 migration defaults to Interval/Balanced and
       preserves owner identity and interval.
PASS - Owner reset clears ownership only and preserves route history, interval,
       wake mode, and Smart sensitivity. Clear-log preserves wake settings.
PASS - Smart source contract covers MPU candidate interrupt, 20 Hz / 5-second
       dynamic-acceleration verification, fresh UTC location acquisition, and
       cooldown/reconfirmation behavior.
PASS - GPS status distinguishes physical supply, receiver activity, UART/parser
       activity, and timed standby; no physical-GPS-power-off capability is
       claimed for the assembled wiring.

NOT PERFORMED / PENDING HARDWARE VALIDATION

PENDING - Inspect the physical assembly: 1000 mAh 1S LiPo to XIAO BAT/GND;
          MPU VCC/GND to 3V3/GND, SDA D4, SCL D5, INT D2, address 0x68; GPS
          VCC/GND to 3V3/GND, TX to D7, RX from D6; D1 unused.
PENDING - On the real MPU6050, verify WHO_AM_I, I²C address, critical register
          read-back, data-ready configuration, and the D2 interrupt.
PENDING - On the real GPS, verify 3.3 V operation, 9600-baud UART wiring,
          NMEA reception, valid RMC/GGA navigation, and fresh UTC fixes.
PENDING - Runtime CAS12 capability check: after normal NMEA, complete two
          controlled standby cycles, observing NMEA silence, resumption, fresh
          RMC/GGA, and subsequent valid navigation for each. Mark the capability
          unavailable if either cycle fails; do not continuously retry it.
PENDING - Measure receiver and whole-device current in Interval and Smart
          states, including BLE connected/disconnected and any timed-standby
          slice. Do not infer battery runtime from nominal capacity.
PENDING - Compare 30, 60, and 120-second standby slices for current and resume
          latency. Thirty seconds is a workaround candidate, not a measured
          optimum.
PENDING - Calibrate Smart sensitivity with an extended stationary run and
          representative walking, city, and smooth-driving runs. The 80/160/300
          mg preset values are starting values only.

BUILD/TOOLING STATUS

PASS - Firmware target compilation completed with Arduino CLI 1.5.1, the
       non-mbed Seeed nRF52 Boards core 1.1.13, FQBN
       Seeeduino:nrf52:xiaonRF52840, TinyGPSPlus 1.0.3, and Adafruit SPIFlash
       5.1.1. Result: 169880 bytes (20%) program storage and 19376 bytes (8%)
       dynamic memory. The temporary toolchain was outside this repository.
PENDING - Android unit-test/APK execution was attempted with Gradle and a
          temporary JDK 17, but stopped before compilation because the Android
          SDK path is unavailable. Protocol tests are present in app/src/test
          and still require an Android SDK-equipped environment to execute.
PENDING - The requested fake-clock firmware state-machine suite and end-to-end
          old-app/new-firmware compatibility tests still require a dedicated
          host-test harness or execution against instrumented hardware.

Until the pending checks are performed on the physical assembly, this release
must not claim measured power savings, battery duration, CAS12 support, or final
motion-threshold calibration.

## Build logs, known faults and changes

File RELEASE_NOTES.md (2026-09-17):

# Android 2.1.2 — Shorter tracking profile labels

- Profile choices show only “Continuous” and “Start & Stop”.
- Descriptions remain below the selector; Start & Stop omits the GPS timeout,
  satellite-count and HDOP sentence. Recording behavior is unchanged.

# Firmware 2.1.2 — Wake flash before startup detection

- Wake the onboard P25Q16H with a GPIO SPI `0xAB` command before initializing
  QSPI. Its deep sleep can survive a CPU reset or USB firmware upload while
  the enclosed tracker stays battery-powered; previously this could stop
  startup with “P25Q16H QSPI flash not detected” before BLE advertising.
- Wait 50 microseconds after the wake command, then initialize flash normally.
  The wake sequence does not erase or write GPS records, settings, or ownership.
- If detection still fails, the repeating fatal message includes the raw JEDEC
  ID and ID-transfer result for diagnosis.
- Android remains 2.1.1 (versionCode 22); no app update is required.

# 2.1.1 — Bluetooth startup and scan recovery

- Valid older tracker settings now load without a mandatory flash erase/write
  before Bluetooth starts. The next successful settings or owner save writes
  metadata v3. Owner identity, saved interval, and sensitivity are preserved.
- Android scan sessions now cancel their own timeout and ignore stale callbacks.
  A connection/pairing failure or scan error is no longer overwritten by
  “XIAO-GPS not found,” and a previous scan cannot stop a subsequent scan.
- Firmware checks Bluetooth stack, UART service, and advertising startup results.
  Fatal startup messages repeat for a Serial Monitor opened after boot; periodic
  diagnostics report actual advertising and connection state. Pairing PINs are
  no longer included in serial output.

# 2.1.0 — Point-to-point tracking

- Smart Motion now offers Continuous and Point-to-point profiles in the app,
  replacing the motion-sensitivity picker. Existing sensitivity is preserved.
- Point-to-point captures after confirmed departure and after ten minutes with
  no acceleration. New acceleration resets the stop timer or cancels an arrival
  acquisition. There are no periodic points during a journey.
- Point-to-point waits up to five minutes for fresh GPS with at least six
  satellites and HDOP at most 1.50. Failed attempts are bounded; stationary
  points are not repeatedly attempted. Accuracy remains reception-dependent.
- Metadata v3 preserves owner, interval, and calibration while migrating older
  settings to Continuous. Smart protocol v3 appends the profile; the app also
  supports v2 firmware, with Continuous available until a firmware update.
- Firmware host checks cover stop timing, rollover, GPS quality, persistence,
  and legacy Continuous regressions. Physical board validation remains pending.

# Release 2.0.0 — Smart Motion

Smart Motion v2.0 adds motion-triggered logging while retaining the existing
offline GPS log, bonded BLE ownership, synchronization, exports, and Interval
mode.

## Firmware

- Firmware version `2.0.0`.
- Added persisted wake modes: `Interval (0)` and `Smart (1)`.
- Interval mode retains the six existing schedules: 60, 900, 1800, 3600,
  7200, and 10800 seconds.
- Smart mode preserves the saved interval but ignores its scheduler while
  selected. MPU6050 motion verification starts GPS acquisition; a fresh valid
  location and UTC are required before a point is stored.
- Smart defaults to Balanced sensitivity. High, Balanced, and Low starting
  thresholds are 80, 160, and 300 mg respectively; these values still require
  calibration on the assembled hardware.
- A missing MPU, failed identity/configuration check, or failed interrupt
  causes a runtime Interval fallback for that boot while preserving the saved
  Smart selection.
- Upgraded the 32-byte metadata record to version 2 by consuming two reserved
  bytes for `wakeMode` and `smartSensitivity`. Version-1 metadata migrates with
  owner and interval preserved and defaults new fields to Interval/Balanced.
- Owner reset clears only ownership and preserves route history, interval, wake
  mode, and Smart sensitivity. Clear-log also preserves wake settings.
- Updated GPS state reporting to distinguish physical supply, receiver
  activity, UART/parser activity, and receiver-side timed standby. The actual
  build powers the GPS from XIAO `3V3` continuously and has no physical power
  gate.
- Added a guarded CASIC `$PCAS12` timed-standby capability probe. It is used only
  after two complete standby/resumption checks with valid navigation data and
  is an optimization, not a Smart-mode dependency.

## Android

- App version `2.0.0`, versionCode `20`.
- Added Interval/Smart mode selection and Smart sensitivity controls.
- Added Smart status/capability display, including runtime Interval fallback and
  receiver standby status where reported by firmware.
- Retained legacy interval configuration, incremental downloads, GPX/CSV
  exports, bonded pairing, local maps, dark mode, and BLE idle disconnect.
- Legacy apps remain able to bond, read the 65-byte INFO packet, synchronize and
  clear logs, and set Interval schedules; they do not expose Smart controls.

## Protocol

The existing framed protocol and 65-byte INFO response remain compatible. The
v2 extension adds:

```text
CMD_GET_SMART_INFO   = 0x06   payload: empty
CMD_SET_SMART_CONFIG = 0x07   payload: mode:u8, sensitivity:u8 (exactly 2 bytes;
                                  sensitivity 0=High, 1=Balanced, 2=Low)
RSP_SMART_INFO       = 0x85   payload: exactly 12 bytes
```

The `RSP_SMART_INFO` payload fields are, in order:

```text
protocolVersion:u8
mode:u8
sensitivity:u8
motionState:u8
confirmationSeconds:u8
standbySliceSeconds:u8
fixCooldownSeconds:u16 little-endian
cooldownRemainingSeconds:u16 little-endian
flags:u8
lastWakeReason:u8
```

Defined flags are `MPU_PRESENT`, `MPU_INTERRUPT_ARMED`, `CAS12_VERIFIED`,
`CAS12_ACTIVE`, `RUNTIME_INTERVAL_FALLBACK`, and `GPS_RECEIVER_ACTIVE`. There
is no physical-GPS-power-off flag for the v2 assembly. `CMD_SET_INTERVAL (0x05)`
continues to set the persisted interval and explicitly selects Interval mode.
The normal ACK plus Smart Info read-back verifies Smart configuration
persistence.

## Validation and hardware status

The documented assembly is a 1000 mAh 1S LiPo, XIAO nRF52840, GY-521/MPU6050
(`3V3`, `D4` SDA, `D5` SCL, `D2` INT, address `0x68`), and GPS (`3V3`, TX to
`D7`, RX from `D6`). D1 is unused. There is no boost converter, load switch,
GPS ON/OFF connection, or physical GPS power gate.

Software source and protocol checks are separate from field validation. MPU
identity/configuration/interrupt, GPS UART and navigation, CAS12 two-cycle
runtime verification, whole-device current, battery runtime, and Smart
sensitivity calibration remain pending until measured on the physical
assembly. This release makes no fabricated current, runtime, or calibration
claim.

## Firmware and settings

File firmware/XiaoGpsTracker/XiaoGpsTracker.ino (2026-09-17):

/*
  XIAO nRF52840 GPS logger + bonded BLE download

  Target board:
    Seeed XIAO nRF52840
    IMPORTANT: use the non-mbed "Seeed nRF52 Boards" Arduino core.

  GPS wiring:
    GPS TX  -> XIAO D7 / Serial1 RX
    GPS RX  -> XIAO D6 / Serial1 TX
    GPS GND -> XIAO GND
    ATGM336H VCC -> XIAO 3V3 (always powered)
    D1 is unused.

  Motion wiring:
    MPU6050 VCC -> 3V3, GND -> GND, SDA -> D4, SCL -> D5,
    INT -> D2.  The MPU is sampled through direct registers; no sensor
    library is required.

  Libraries:
    TinyGPSPlus
    Adafruit SPIFlash
    Bluefruit52Lib is supplied by the Seeed/Adafruit nRF52 board core.

  BLE:
    Nordic UART Service (NUS)
    Pairing passkey below. CHANGE IT before deployment.
    The first successfully bonded phone becomes the owner.
    Later unknown/unbonded phones are disconnected.  Tracker v2 adds a
    persisted Interval/Smart mode while retaining the v1.5 packet layout.

  Storage:
    Raw circular log in the XIAO's 2 MiB P25Q16H QSPI flash.
    Sector 0 stores tracker metadata (owner phone, GPS interval, and v2
    Interval/Smart configuration).
    Remaining sectors hold 20-byte GPS records in a circular log.
    The GPS interval is configurable from Android: 1 min, 15 min, 30 min,
    1 h, 2 h, or 3 h.
*/

#include <Arduino.h>
#include <Wire.h>
#include <Adafruit_TinyUSB.h>
#include <bluefruit.h>
#include <TinyGPS++.h>
#include <Adafruit_SPIFlash.h>
#include <flash_devices.h>
#include <math.h>

// ---------------- User settings ----------------

static const char BLE_DEVICE_NAME[] = "XIAO-GPS";
static const char FW_VERSION[] = "2.1.2";
static const char BLE_PAIRING_PIN[] = "482731"; // CHANGE THIS, exactly 6 digits
static const uint32_t DEFAULT_LOG_INTERVAL_SECONDS = 1800; // 30 min
static const uint32_t GPS_BAUD = 9600;
static const uint8_t OWNER_RESET_PIN = D0;       // hold to GND at boot
static const uint32_t OWNER_RESET_HOLD_MS = 5000;

// ---------------- Runtime/power profile ----------------
//
// Target: a 1S LiPo on the XIAO battery input; capacity is installation-specific.
//
// The supplied v2 hardware powers the bare ATGM336H from 3V3 continuously.
// gpsPowered below therefore means "the GPS UART/parser is active", never
// "the receiver supply is physically on".  No firmware path claims a physical
// GPS power-off capability on this wiring.
static const bool POWER_OPTIMIZATION_ENABLED = true;
static const bool GPS_POWER_CONTROL_ENABLED = false;
static const bool GPS_SUPPLY_ALWAYS_ON = true;

// For intervals longer than one minute the GPS UART is normally closed.
// It reopens this many seconds before the next point is due.  The receiver
// itself remains supplied, so this is a runtime/parser optimization rather
// than a physical power gate.
//
// The 1-minute profile intentionally keeps the GPS powered after the first fix.
// With this 5-pin carrier there is no exposed VBAT, so repeatedly cold-starting
// every minute is both unreliable and often less efficient than staying locked.
static const uint32_t GPS_ACQUIRE_LEAD_SECONDS = 60;
static const uint32_t GPS_ACQUIRE_TIMEOUT_MS = 120000;
static const uint32_t GPS_RETRY_SLEEP_MS = 60000;
static const uint32_t GPS_POWER_SETTLE_MS = 250;

// ---------------- Smart Motion v2 ----------------
//
// MPU6050 register settings: ±2 g accelerometer, ±250 dps gyroscope, DLPF
// enabled, and a 20 Hz data-ready source for verification.  Smart's armed
// state uses the MPU's own 5 Hz accelerometer-only cycle; the MCU performs no
// periodic armed-state sample reads.  Verification consumes one raw sample
// every 50 ms (20 Hz), then removes gravity in software.
static const uint8_t MPU6050_ADDRESS = 0x68;
static const uint8_t MPU_SDA_PIN = D4;
static const uint8_t MPU_SCL_PIN = D5;
static const uint8_t MPU_INT_PIN = D2;
static const uint8_t MPU_REG_SMPLRT_DIV = 0x19;
static const uint8_t MPU_REG_CONFIG = 0x1A;
static const uint8_t MPU_REG_GYRO_CONFIG = 0x1B;
static const uint8_t MPU_REG_ACCEL_CONFIG = 0x1C;
static const uint8_t MPU_REG_MOT_THR = 0x1F;
static const uint8_t MPU_REG_MOT_DUR = 0x20;
static const uint8_t MPU_REG_INT_STATUS = 0x3A;
static const uint8_t MPU_REG_INT_PIN_CFG = 0x37;
static const uint8_t MPU_REG_INT_ENABLE = 0x38;
static const uint8_t MPU_REG_ACCEL_XOUT_H = 0x3B;
static const uint8_t MPU_REG_MOT_DETECT_CTRL = 0x69;
static const uint8_t MPU_REG_PWR_MGMT_1 = 0x6B;
static const uint8_t MPU_REG_PWR_MGMT_2 = 0x6C;
static const uint8_t MPU_REG_WHO_AM_I = 0x75;

// Armed mode is handled inside the MPU's low-power accelerometer cycle.  The
// MCU performs no periodic acceleration reads in that state; it wakes only
// when the latched motion interrupt asserts.  Verification then changes to a
// 20 Hz data-ready profile and reads acceleration in the MCU loop.
static const uint32_t SMART_VERIFY_WINDOW_MS = 5000; // confirmationSeconds
// A nominal 100th sample can arrive just after 5 s because the interrupt and
// I2C read are asynchronous.  The sample count, not this watchdog, defines
// the confirmation window; the watchdog only rejects a candidate that never
// produces all 100 samples.
// Allow only 100 ms of loop/interrupt servicing tolerance beyond the nominal
// 5-second, 100-sample window.  This prevents a slower 16-19 Hz stream from
// being accepted as the configured 20 Hz confirmation profile.
static const uint32_t SMART_VERIFY_WATCHDOG_MS = 5100;
static const uint16_t SMART_VERIFY_REQUIRED_ACTIVE_SAMPLES = 60;
static const uint16_t SMART_VERIFY_TOTAL_SAMPLES = 100;
static const uint32_t SMART_VERIFY_MAX_QUIET_GAP_MS = 1000;
static const uint32_t SMART_QUIET_GAP_MS = 2000;
static const uint32_t SMART_MOTION_RECENCY_MS = 1500;
static const uint32_t SMART_ACQUISITION_TIMEOUT_MS = 90000;
static const uint32_t SMART_COOLDOWN_MS = 120000;
// Point-to-point records departure and arrival only. Quality limits are
// acquisition criteria, not a guarantee of measured positional accuracy.
static const uint8_t SMART_PROFILE_CONTINUOUS = 0;
static const uint8_t SMART_PROFILE_POINT_TO_POINT = 1;
static const uint32_t SMART_POINT_STOP_MS = 600000;
static const uint32_t SMART_POINT_ACQUISITION_TIMEOUT_MS = 300000;
static const uint8_t SMART_POINT_MIN_SATELLITES = 6;
static const uint16_t SMART_POINT_MAX_HDOP_X100 = 150;
static const uint32_t SMART_POINT_FIX_STALE_MS = 2000;
// Keep the UART/parser open for the final 10 seconds of every Smart cooldown.
// This observation window is deliberately short so it does not turn cooldown
// into a full-time receiver session, but is long enough for fresh 1 Hz RMC/GGA
// fixes before the cooldown classifier runs.
static const uint32_t SMART_COOLDOWN_GNSS_OBSERVATION_MS = 10000;
// Receiver-side standby is selected at build time because current draw and
// resume latency must be measured on the actual ATGM336H assembly first.  The
// 60-second default is deliberately provisional; a build may select only one
// of the measured 30/60/120-second profiles with
// -DSMART_STANDBY_SLICE_SECONDS_CONFIG=30, 60, or 120.
#ifndef SMART_STANDBY_SLICE_SECONDS_CONFIG
#define SMART_STANDBY_SLICE_SECONDS_CONFIG 60U
#endif
static_assert(SMART_STANDBY_SLICE_SECONDS_CONFIG == 30U ||
              SMART_STANDBY_SLICE_SECONDS_CONFIG == 60U ||
              SMART_STANDBY_SLICE_SECONDS_CONFIG == 120U,
              "SMART_STANDBY_SLICE_SECONDS_CONFIG must be 30, 60, or 120");
static const uint16_t SMART_STANDBY_SLICE_SECONDS =
    (uint16_t)SMART_STANDBY_SLICE_SECONDS_CONFIG;
static const uint16_t SMART_FIX_COOLDOWN_SECONDS = 120;
static const uint32_t SMART_GNSS_CONTINUED_SPEED_CM_S = 100; // 1 m/s
static const uint32_t SMART_GNSS_STALE_MS = 5000;
// GNSS displacement is an independent continued-motion signal.  A 20 m
// threshold is conservative for consumer GNSS noise and is evaluated only
// with a fresh, navigation-valid fix and the reference from the last stored
// Smart fix (or the most recent cooldown classification).
static const float SMART_GNSS_CONTINUED_DISPLACEMENT_METERS = 20.0f;
static const uint8_t SMART_GNSS_MIN_SATELLITES = 4;
static const uint16_t SMART_GNSS_MAX_HDOP_X100 = 300; // HDOP <= 3.00
static const uint8_t SMART_DEFAULT_SENSITIVITY = 1;
static const uint8_t SMART_MAX_SENSITIVITY = 2;
static const uint16_t SMART_HIGH_THRESHOLD_MG = 80;
static const uint16_t SMART_BALANCED_THRESHOLD_MG = 160;
static const uint16_t SMART_LOW_THRESHOLD_MG = 300;

// PS-MPU-6000A-00 rev 3.3, section 8.1: the low-power wake profile
// uses DLPF_CFG=0 and MOT_DUR=1. A 100-count hardware filter must not
// be treated as a 100 ms debounce in the 5 Hz cycle profile. The five-second
// software verifier rejects bumps after this deliberately permissive wake.
static const uint8_t MPU_MOTION_DURATION = 1;
static const uint8_t MPU_CONFIG_ARMED = 0x00;
// The rev 3.3 low-power motion flowchart specifies 32 mg/LSB. Older
// documentation/examples disagree on this scale, so field calibration on the
// actual module is still required. This is a permissive wake threshold only;
// the 20 Hz software verifier uses raw acceleration and the exact mg preset.
static const uint8_t MPU_MOTION_THRESHOLD_MG_PER_LSB = 32;
static const uint8_t MPU_MOTION_DETECT_CTRL = 0x00;
static const uint8_t MPU_INT_PIN_CFG_LATCHED_ACTIVE_HIGH = 0x20;
static const uint8_t MPU_INT_ENABLE_MOTION = 0x40;
static const uint8_t MPU_INT_ENABLE_DATA_READY = 0x01;
static const uint8_t MPU_INT_STATUS_MOTION = 0x40;
static const uint8_t MPU_INT_STATUS_DATA_READY = 0x01;
static const uint8_t MPU_PWR_MGMT_1_ARMED = 0x28; // CYCLE + TEMP_DIS
static const uint8_t MPU_PWR_MGMT_1_VERIFY = 0x08; // active, TEMP_DIS
// PWR_MGMT_2: LP_WAKE_CTRL=01 selects 5 Hz (bits 7..6), accelerometer
// standby is bits 5..3, and gyro standby is bits 2..0.  Thus 0x47 is the
// accel-only 5 Hz armed profile and 0x07 keeps the accel active for verify.
static const uint8_t MPU_PWR_MGMT_2_ARMED = 0x47;
static const uint8_t MPU_PWR_MGMT_2_VERIFY = 0x07;
static const uint8_t MPU_ACCEL_CONFIG_ARMED = 0x07; // DHPF hold initial gravity
static const uint8_t MPU_ACCEL_CONFIG_VERIFY = 0x00; // ±2 g, raw data for LPF
static const uint8_t MPU_MOTION_THRESHOLD_REGISTER_MAX = 255;

// CAS12 is an optional receiver-side standby optimization.  It is probed only
// after NMEA has been observed and must pass two complete silence/resumption
// cycles (including fresh RMC+GGA navigation) before use.  Smart never depends
// on this optimization: UART inactivity remains the fallback.
static const uint16_t CAS12_PROBE_STANDBY_SECONDS = 5;
static const uint32_t CAS12_PROBE_QUIET_GAP_MS = 1500;
static const uint32_t CAS12_PROBE_RESUME_TIMEOUT_MS = 7000;
static const uint32_t CAS12_PROBE_MIN_ELAPSED_MS =
    (uint32_t)CAS12_PROBE_STANDBY_SECONDS * 1000UL;
static const uint32_t CAS12_PROBE_CYCLE_TIMEOUT_MS =
    CAS12_PROBE_MIN_ELAPSED_MS + CAS12_PROBE_RESUME_TIMEOUT_MS;
static const uint32_t CAS12_NMEA_WAIT_TIMEOUT_MS = 15000;

// Release build logging: serial diagnostics are automatically enabled on USB
// power, but stay disabled on battery so TinyUSB/printing does not waste energy.
static const bool DEBUG_SERIAL_ON_USB = true;

// XIAO nRF52840 supports 50 mA / 100 mA charging. 50 mA is intentionally used
// for the current 1000 mAh assembly's charge profile.
static const bool LIMIT_LIPO_CHARGE_TO_50MA = true;

// Seeed's nRF52 XIAO variant exposes the onboard HICHG selector as
// PIN_CHARGING_CURRENT. Older board-core revisions may omit the macro even
// though Arduino pin index 22 still maps to physical P0.13 / HICHG.
#ifndef PIN_CHARGING_CURRENT
#define PIN_CHARGING_CURRENT 22
#endif

// ---------------- GPS ----------------

TinyGPSPlus gps;

// ---------------- QSPI flash ----------------

Adafruit_FlashTransport_QSPI flashTransport;
Adafruit_SPIFlash flash(&flashTransport, false /* no 4 KiB cache */);

static const SPIFlash_Device_t flashDevices[] = { P25Q16H };

static const uint32_t FLASH_SIZE_BYTES = 2UL * 1024UL * 1024UL;
static const uint32_t SECTOR_SIZE = 4096;
static const uint32_t SECTOR_COUNT = FLASH_SIZE_BYTES / SECTOR_SIZE;

// Physical QSPI sector 0 is reserved for tracker metadata.
// GPS circular-log data uses sectors 1..511.
static const uint32_t METADATA_SECTOR = 0;
static const uint32_t LOG_SECTOR_FIRST = 1;
static const uint32_t LOG_SECTOR_COUNT = SECTOR_COUNT - LOG_SECTOR_FIRST;

// v1.0 legacy owner record magic and combined metadata magic. Metadata v3
// consumes three bytes that v1.5 left reserved, so owner,
// interval, and the 20-byte log records remain byte-for-byte compatible.
static const uint32_t LEGACY_OWNER_MAGIC = 0x314E574FUL; // "OWN1"
static const uint32_t METADATA_MAGIC = 0x354B5254UL;     // "TRK5"
static const uint8_t METADATA_VERSION_V1 = 1;
static const uint8_t METADATA_VERSION_V2 = 2;
static const uint8_t METADATA_VERSION_V3 = 3;
static const uint8_t METADATA_RESERVED_MODE = 0;
static const uint8_t METADATA_RESERVED_SENSITIVITY = 1;
static const uint8_t METADATA_RESERVED_PROFILE = 2;

#pragma pack(push, 1)
struct LegacyOwnerRecord {
  uint32_t magic;
  uint8_t version;
  uint8_t addrType;
  uint8_t addr[6];
  uint8_t reserved[3];
  uint8_t crc8;
};

struct MetadataRecord {
  uint32_t magic;
  uint8_t version;
  uint8_t ownerSet;
  uint8_t addrType;
  uint8_t addr[6];
  uint32_t logIntervalSeconds;
  uint8_t reserved[14];
  uint8_t crc8;
};

struct GpsRecord {
  uint32_t seq;
  uint32_t epoch;       // UTC Unix epoch seconds
  int32_t latE7;        // latitude * 10^7
  int32_t lonE7;        // longitude * 10^7
  uint16_t hdopX100;    // TinyGPS++ HDOP raw value (hundredths)
  uint8_t satellites;
  uint8_t crc8;         // CRC-8 over bytes 0..18
};
#pragma pack(pop)

static_assert(sizeof(LegacyOwnerRecord) == 16, "LegacyOwnerRecord must stay 16 bytes");
static_assert(sizeof(MetadataRecord) == 32, "MetadataRecord must stay 32 bytes");
static_assert(sizeof(GpsRecord) == 20, "GpsRecord must stay 20 bytes");

enum TrackingMode : uint8_t {
  TRACKING_INTERVAL = 0,
  TRACKING_SMART = 1
};

enum SmartState : uint8_t {
  SMART_DISABLED = 0,
  SMART_ARMED = 1,
  SMART_VERIFYING = 2,
  SMART_ACQUIRING = 3,
  SMART_TRACKING = 4,
  SMART_COOLDOWN = 5,
  SMART_WAITING_FOR_STOP = 6,
  SMART_ACQUIRING_STOP = 7
};

enum Cas12State : uint8_t {
  CAS12_UNKNOWN = 0,
  CAS12_PROBING = 1,
  CAS12_SUPPORTED = 2,
  CAS12_UNSUPPORTED = 3
};

enum SmartWakeReason : uint8_t {
  SMART_WAKE_NONE = 0,
  SMART_WAKE_MOTION = 1,
  SMART_WAKE_RETRY = 2,
  SMART_WAKE_STOP = 3
};

static const uint32_t RECORD_SIZE = sizeof(GpsRecord);
static const uint32_t RECORDS_PER_SECTOR = SECTOR_SIZE / RECORD_SIZE; // 204
static const uint32_t LOG_CAPACITY =
    RECORDS_PER_SECTOR * LOG_SECTOR_COUNT; // 104244 (~72.4 days @ 1/min)

static uint8_t sectorBuffer[RECORDS_PER_SECTOR * RECORD_SIZE];

static MetadataRecord metadataRecord = {};
static bool ownerSet = false;
static bool ownerResetRequested = false;
static uint32_t logIntervalSeconds = DEFAULT_LOG_INTERVAL_SECONDS;
static TrackingMode trackingMode = TRACKING_INTERVAL;
// Smart sensitivity is persisted in MetadataRecord.reserved[1].  Values are
// intentionally bounded so an all-0xFF/corrupt record cannot select an
// undocumented classifier profile.
static uint8_t smartSensitivity = SMART_DEFAULT_SENSITIVITY;
static uint8_t smartTrackingProfile = SMART_PROFILE_CONTINUOUS;
// A Smart selection remains persisted when the motion hardware is unavailable,
// but this boot deliberately runs the proven Interval scheduler.  Keeping the
// fallback separate from trackingMode lets INFO/0x85 report the saved mode
// and the runtime limitation truthfully.
static bool runtimeIntervalFallback = false;

static uint32_t newestSeq = 0;
static uint32_t storedCount = 0;
static uint32_t lastStoredEpoch = 0;
static GpsRecord newestRecord = {};
static uint32_t lastGpsDiagMs = 0;
static bool firstGpsDiag = true;

static bool debugSerialActive = false;
// Logical GPS runtime state: true means Serial1 is open and this sketch is
// accepting NMEA.  The actual receiver supply is always on for v2 hardware.
static bool gpsPowered = false;
static bool gpsEverHadFix = false;
static uint32_t gpsAcquireStartedMs = 0;
static uint32_t gpsNextWakeMs = 0;
// Monotonic firmware-owned location-update counter.  TinyGPS++ exposes a
// latched location freshness bit; serviceGps() consumes that bit by calling
// the non-const lat()/lng() accessors and advances this counter only alongside
// a newly counted valid-fix sentence.
static uint32_t gpsLocationUpdateCounter = 0;
// Date/time freshness is tracked separately so a post-start GGA cannot pair
// a new coordinate with UTC that was cached before acquisition began.
static uint32_t gpsUtcUpdateCounter = 0;
static bool flashSleeping = false;

// ---------------- MPU6050 / Smart runtime ----------------

volatile bool mpuDataReadyPending = false;
volatile uint32_t mpuIrqCount = 0;
static uint32_t mpuMotionEventCount = 0;
static uint8_t mpuLastInterruptStatus = 0;
static bool mpuAvailable = false;
static bool mpuInterruptAttached = false;
static bool mpuSampleInitialized = false;
static uint32_t mpuLastSampleMs = 0;
static uint32_t mpuLastMotionMs = 0;
static uint32_t mpuQuietSinceMs = 0;
static float mpuGravityX = 0.0f;
static float mpuGravityY = 0.0f;
static float mpuGravityZ = 0.0f;
static uint16_t mpuDynamicMagnitudeMg = 0;

static SmartState smartState = SMART_DISABLED;
static uint32_t smartStateSinceMs = 0;
static uint32_t smartAcquisitionStartedMs = 0;
static uint32_t smartCooldownUntilMs = 0;
static uint32_t smartLastMotionMs = 0;
static bool smartRetryAfterCooldown = false;
static bool smartFirstFixPending = false;
static uint32_t smartAcquisitionFixSentenceBaseline = 0;
static uint32_t smartAcquisitionLocationBaseline = 0;
static uint32_t smartAcquisitionUtcBaseline = 0;
static bool smartAcquisitionNmeaSynchronized = true;
static bool smartStartupProbePending = false;
static bool smartMotionDetected = false;
static bool smartCooldownObservationOpen = false;
static uint32_t smartVerifyStartedMs = 0;
static uint16_t smartVerifyPeakMg = 0;
static uint16_t smartVerifySamples = 0;
static uint16_t smartVerifyActiveSamples = 0;
static uint32_t smartVerifyLastActiveMs = 0;
static SmartWakeReason lastWakeReason = SMART_WAKE_NONE;

// The acquisition fix is the displacement baseline.  It is intentionally
// retained through the 120 s cooldown while fresh GNSS is observed, then
// advanced after the cooldown classification so repeated checks measure a new
// interval instead of accumulating distance from boot.
static bool smartMotionReferenceValid = false;
static double smartMotionReferenceLat = 0.0;
static double smartMotionReferenceLon = 0.0;
static uint32_t smartMotionReferenceEpoch = 0;

// ---------------- NMEA/CAS12 runtime probe ----------------

static bool nmeaSeen = false;
static uint32_t lastNmeaByteMs = 0;
static uint32_t nmeaByteCount = 0;
static uint8_t nmeaHeader[6] = {};
static uint8_t nmeaHeaderLength = 0;
static bool nmeaInSentence = false;
static uint32_t nmeaRmcCount = 0;
static uint32_t nmeaGgaCount = 0;
static uint32_t nmeaRmcCountAtProbe = 0;
static uint32_t nmeaGgaCountAtProbe = 0;
static uint32_t nmeaBytesAtProbe = 0;
static bool cas12ProbeAttempted = false;
static uint8_t cas12ProbeCycle = 0;
static uint8_t cas12ProbePhase = 0;
static uint32_t cas12ProbeCycleStartedMs = 0;
static bool cas12ProbeQuietObserved = false;
static uint32_t cas12StartupSinceMs = 0;
static Cas12State cas12State = CAS12_UNKNOWN;
static bool cas12NmeaConfigured = false;
static bool gpsStandby = false;
static bool gpsStandbyPending = false;
static uint32_t gpsStandbyRequestedMs = 0;
static uint32_t gpsStandbyUntilMs = 0;

// ---------------- BLE ----------------

BLEUart bleuart;
static uint16_t activeConnHandle = BLE_CONN_HANDLE_INVALID;

// Framed protocol
static const uint8_t MAGIC1 = 0xA5;
static const uint8_t MAGIC2 = 0x5A;

enum MessageType : uint8_t {
  CMD_INFO_REQ       = 0x01,
  CMD_DOWNLOAD_REQ   = 0x02,
  CMD_CLEAR_LOG_REQ  = 0x03,
  CMD_PING           = 0x04,
  CMD_SET_INTERVAL   = 0x05,
  CMD_GET_SMART_INFO  = 0x06,
  CMD_SET_SMART_CONFIG = 0x07,

  RSP_INFO           = 0x81,
  RSP_DATA_BATCH     = 0x82,
  RSP_DOWNLOAD_DONE  = 0x83,
  RSP_ACK            = 0x84,
  RSP_SMART_INFO     = 0x85,
  RSP_ERROR          = 0xFF
};

enum ErrorCode : uint8_t {
  ERR_PAIR_REQUIRED = 1,
  ERR_BAD_COMMAND   = 2,
  ERR_BAD_PAYLOAD   = 3,
  ERR_FLASH         = 4,
  ERR_BUSY          = 5,
  ERR_BAD_INTERVAL   = 6,
  ERR_BAD_MODE       = 7,
  ERR_BAD_SENSITIVITY = 8,
  ERR_SMART_STATUS   = 9
};

// RSP_SMART_INFO (0x85) flags.  Its payload is always exactly 12 bytes; these
// bits occupy only byte 10, leaving bytes 0..9 and 11 stable for the protocol.
static const uint8_t SMART_INFO_FLAG_MPU_PRESENT = 0x01;
static const uint8_t SMART_INFO_FLAG_MPU_INTERRUPT_ARMED = 0x02;
static const uint8_t SMART_INFO_FLAG_CAS12_VERIFIED = 0x04;
static const uint8_t SMART_INFO_FLAG_CAS12_ACTIVE = 0x08;
static const uint8_t SMART_INFO_FLAG_RUNTIME_INTERVAL_FALLBACK = 0x10;
static const uint8_t SMART_INFO_FLAG_GPS_RECEIVER_ACTIVE = 0x20;
static const uint8_t SMART_INFO_PROTOCOL_VERSION = 3;
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
void loop() {
  serviceGpsPowerState();
  serviceMpu();
  serviceGps();
  serviceCas12Probe();
  serviceSmartState();
  serviceGpsDiagnostics();
  serviceBleRx();
  serviceDownload();

  if (downloadActive || activeConnHandle != BLE_CONN_HANDLE_INVALID) {
    delay(2);
  } else if (gpsPowered) {
    delay(10);
  } else {
    delay(25);
  }
}

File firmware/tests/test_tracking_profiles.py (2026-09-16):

#!/usr/bin/env python3
"""Host checks of the sketch's actual profile persistence and GPS-save paths.

Requires g++. Fake flash, navigation fields, and UART isolate boundary behavior;
this does not emulate NMEA decoding or physical peripherals.
"""
from pathlib import Path
import re
import subprocess
import tempfile

source = (Path(__file__).resolve().parents[1] /
          'XiaoGpsTracker/XiaoGpsTracker.ino').read_text()


def function(name):
    match = re.search(r'^\w+ ' + name + r'\([^\n]*\) \{', source, re.M)
    assert match, name
    end = source.index('{', match.start()) + 1
    depth = 1
    while depth:
        depth += (source[end] == '{') - (source[end] == '}')
        end += 1
    return source[match.start():end]


constants = '\n'.join(re.findall(
    r'^static const (?:uint\d+_t|float|bool) (?:SMART_|MPU_|GPS_|POWER_|METADATA_|LEGACY_OWNER_|DEFAULT_LOG_)[\s\S]*?;',
    source, re.M))
types = source[source.index('#pragma pack(push, 1)'):source.index('static const uint32_t RECORD_SIZE')]
preamble = r'''
#include <cassert>
#include <cstdint>
#include <cstdio>
#include <cstring>
#include <algorithm>
using std::min;
#define D2 2
#define D4 4
#define D5 5
#define SMART_STANDBY_SLICE_SECONDS_CONFIG 60U
#define DBG_PRINTF(...) ((void)0)
#define DBG_PRINTLN(...) ((void)0)
uint32_t fakeNow = 10000;
uint32_t millis() { return fakeNow; }
'''
fakes = r'''
static const uint32_t SECTOR_SIZE = 4096;
MetadataRecord disk{}, metadataRecord{};
struct FakeFlash {
  bool fail = false;
  int erases = 0, writes = 0;
  bool eraseSector(int) { erases++; return !fail; }
  void waitUntilReady() {}
  size_t writeBuffer(int, const uint8_t* data, size_t n) {
    writes++; memcpy(&disk, data, n); return n;
  }
  size_t readBuffer(int, uint8_t* data, size_t n) {
    memcpy(data, &disk, n); return n;
  }
} flash;
void flashWake() {}
void flashSleep() {}
bool ownerSet;
uint32_t logIntervalSeconds;
TrackingMode trackingMode;
uint8_t smartSensitivity, smartTrackingProfile;
SmartState smartState;
SmartWakeReason lastWakeReason;
bool runtimeIntervalFallback;
Cas12State cas12State = CAS12_UNKNOWN;
bool smartStartupProbePending, cas12ProbeAttempted;
void finishCas12Probe(bool supported) {
  cas12State = supported ? CAS12_SUPPORTED : CAS12_UNSUPPORTED;
}
int resets = 0;
void applyTrackingRuntime() { resets++; smartState = SMART_ARMED; }
void cancelCas12ProbeForModeChange() {}
bool gpsPowered, gpsStandby, gpsStandbyPending, smartFirstFixPending;
bool smartRetryAfterCooldown, smartMotionDetected, smartAcquisitionNmeaSynchronized;
bool gpsEverHadFix;
uint32_t smartAcquisitionStartedMs, smartLastMotionMs, mpuQuietSinceMs;
uint32_t smartAcquisitionFixSentenceBaseline, smartAcquisitionLocationBaseline;
uint32_t smartAcquisitionUtcBaseline, gpsLocationUpdateCounter, gpsUtcUpdateCounter;
uint32_t gpsAcquireStartedMs, lastStoredEpoch;
int writes = 0, gnssCalls = 0;
bool appendOk = true;
struct Field {
  bool valid = true;
  uint32_t raw = 1, old = 0;
  bool isValid() { return valid; }
  uint32_t age() { return old; }
  uint32_t value() { return raw; }
  double lat() { return 45.0; }
  double lng() { return 9.0; }
};
struct FakeGps {
  Field location, date, time, hdop, satellites;
  uint32_t fixes = 10;
  uint32_t sentencesWithFix() { return fixes; }
  void encode(char) { fixes++; }
} gps;
struct FakeSerial {
  bool pending = false;
  bool available() { return pending; }
  char read() { pending = false; return '$'; }
} Serial1;
void observeNmeaByte(char) {}
bool consumeGpsLocationFreshness() { return true; }
bool consumeGpsUtcFreshness() { return true; }
uint32_t gpsEpochUtc() { return 1700000000 + fakeNow / 1000; }
bool appendRecord(GpsRecord&) { if (appendOk) writes++; return appendOk; }
void setSmartState(SmartState state) { smartState = state; }
void gpsPowerOn() { gpsPowered = true; }
void gpsPowerOff() { gpsPowered = gpsStandby = gpsStandbyPending = false; }
void discardPendingGpsInputAtAcquisitionStart() {
  Serial1.pending = false; smartAcquisitionNmeaSynchronized = false;
}
bool configureMpuArmed() { return true; }
void disableSmartMpuRuntime() { runtimeIntervalFallback = true; }
void updateSmartMotionReferenceFromRecord(const GpsRecord&) {}
void gnssContinuedMotion(uint32_t) { gnssCalls++; smartLastMotionMs = fakeNow; }
void enterSmartCooldown(bool) { smartState = SMART_COOLDOWN; }
void scheduleAfterSavedFix() {}
void scheduleGpsSleep(uint32_t) {}
'''
names = ['crc8', 'timeReached', 'elapsedMs', 'isAllowedLogInterval',
         'legacyOwnerRecordValid', 'metadataRecordValid', 'initDefaultMetadata',
         'persistMetadata', 'loadOwnerLock', 'setSmartConfig', 'clearOwnerLock',
         'smartRuntimeActive', 'smartPointToPoint', 'smartAcquisitionActive',
         'smartAcquisitionTimeoutMs', 'startSmartAcquisition',
         'finishSmartPointAcquisition', 'smartPointFixQualityAcceptable', 'serviceGps']
tests = r'''
void seal(MetadataRecord& value) {
  value.crc8 = crc8(reinterpret_cast<const uint8_t*>(&value), sizeof(value) - 1);
}
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

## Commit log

2026-08-17 Enclosure 3D files
    [Seeed_GPS_Tracker.3mf, Seeed_GPS_Tracker.f3z, Seeed_GPS_Tracker.stl]
2026-09-16 Fix Smart motion rearming and show mode-specific Android controls
    [XiaoGpsTracker.ino, test_motion_runtime.py]
2026-09-16 Fix BLE startup migration and Android scan lifecycle
    [XiaoGpsTracker.ino, test_tracking_profiles.py]
2026-09-17 Wake QSPI flash before detection after powered resets
    [XiaoGpsTracker.ino, test_flash_startup.py]
